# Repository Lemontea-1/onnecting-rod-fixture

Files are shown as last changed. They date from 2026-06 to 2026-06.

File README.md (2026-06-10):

# 🔧 连杆钻孔夹具设计 / Connecting Rod Drilling Fixture Design

> **广东理工学院 · 机械设计制造及其自动化 · 夹具课程设计**
> 
> Guangdong Polytechnic Institute — Mechanical Design, Manufacturing & Automation — Fixture Design Project

---

## 📋 项目概述 / Project Overview

本项目为一套**连杆大头孔钻—铰加工专用夹具**，用于在 **Z525立式钻床** 上完成45钢连杆大头孔 **Φ28H7** 的钻削（Φ27底孔）和铰削（Φ28H7精加工）。

夹具采用 **"一面两V形块"定位 + 螺旋压板夹紧 + 可换钻套引导** 的经典方案，结构紧凑、操作方便，适用于中批量生产（年产5000~10000件）。

---

## 📐 技术参数 / Technical Parameters

| 项目 | 参数 |
|---|---|
| 🔩 **工件** | 连杆（45钢调质，HB220~250） |
| 📏 **工件尺寸** | 总长143mm，大端Φ70，小端Φ40，厚度20mm |
| 🎯 **加工内容** | 钻Φ27底孔 → 铰Φ28H7精孔 |
| ⚙️ **机床** | Z525立式钻床（2.8kW，莫氏3号锥孔） |
| 📦 **生产批量** | 中批量（5000~10000件/年） |
| 🔒 **夹紧方式** | 螺旋压板手动夹紧（自锁型） |
| 📍 **定位方式** | 一面（底面）+ 两V形块（大端Φ70 + 小端Φ40） |
| 🎯 **钻套引导** | 可换钻套（Φ27钻孔 + Φ28铰孔）快换式 |

---

## 🏗️ 夹具结构说明 / Fixture Structure

### 📍 定位系统 — "一面两V形块"

| 自由度 | 约束方式 | 定位元件 | 说明 |
|---|---|---|---|
| Z移动 | ✅ | 底板顶面 | 工件底面平放在底板上 |
| X转动 | ✅ | 底板顶面 | 大面积平面限制 |
| Y转动 | ✅ | 底板顶面 | 大面积平面限制 |
| X移动 | ✅ | 大V形块 | Φ70外圆90°V形槽定心 |
| Y移动 | ✅ | 大V形块 | Φ70外圆90°V形槽定心 |
| Z转动 | ✅ | 小V形块 | Φ40外圆V形槽止转 |

**设计要点：**
- 遵循 **"基准重合"** 原则，定位基准 = 设计基准 → ΔB = 0
- V形块自动定心，定位精度高，总定位误差仅 **0.021mm**
- V形块材料45钢，表面淬火HRC48~52，V形面磨削Ra≤0.8μm

### 🔒 夹紧系统 — 螺旋压板夹紧

```
         ┌──────────┐
         │  M20螺母  │ ← 扳手施力
         ├──────────┤
    ┌────┤   压板   ├────┐
    │    └──────────┘    │
    │                    │
 支撑螺钉             工件大端
 (支点)              (夹紧点)
```

**选型论证：**

| 方案 | 优点 | 缺点 | 结论 |
|---|---|---|---|
| 🔩 螺旋压板 | 夹紧力大、自锁、成本低 | 动作较慢 | ✅ **采用** |
| ⚡ 偏心夹紧 | 动作快 | 力小、自锁差、怕振动 | ❌ 不适合钻削 |
| 💨 气动夹紧 | 力稳定、高效 | 需气源、成本高 | ❌ 中批量不经济 |

**关键参数：**
- 压板尺寸：100×74×15mm（短压板，仅压大端）
- T形螺栓：M20，23×20×86mm，头部在底板T形槽内滑动
- 杠杆比：≈2∶1（放大螺栓拉力）
- 安全系数：K=2.5

### 🎯 引导系统 — 快换钻套 + 双工位钻模板

```
    钻模板 (140×60×15)
  ┌──────────────────────┐
  │  ┌─────┐  ┌─────┐   │
  │  │Φ27套│  │Φ28套│   │ ← 中心距50mm
  │  │钻孔 │  │铰孔 │   │
  │  └─────┘  └─────┘   │
  └──────────────────────┘
       ↑ 4×M8螺栓固定在底板上
```

**设计亮点：**
- 🔄 **快换钻套**：Φ27和Φ28钻套外径相同（Φ42），轻松互换
- ⚡ **双工位**：钻模板双孔设计，一次装夹完成钻→铰两道工序
- 💪 **T10A材料**：淬火HRC62，耐磨性优异
- 📐 **钻模板刚度**：最大挠度0.088mm < 许用挠度0.14mm

---

## 📦 零件清单 / Parts List

| 编号 | 名称 | 材料 | 数量 | 规格/尺寸 |
|---|---|---|:---:|---|
| 01 | 🔩 连杆（工件） | 45钢调质 | 1 | 143×70×20mm，大孔Φ28H7/小孔Φ20H7 |
| 02 | 📐 底板 | 45钢调质 | 1 | 200×200×30mm，含Φ32间隙孔、T形槽 |
| 03 | 🔺 大V型定位块 | 45钢 HRC48~52 | 1 | 20×85×30mm，V形槽90° |
| 04 | 🔺 小V型定位块 | 45钢 HRC48~52 | 1 | 22×56×20mm，V形槽90° |
| 05 | 📏 压板 | 45钢调质 | 1 | 100×74×15mm，D=30螺栓孔 |
| 06 | 🔩 T形螺栓 | 45钢调质 | 1 | M20×86mm，T头23×30×10mm |
| 07 | 🎯 Φ27钻套 | T10A HRC62 | 1 | 内Φ27/外Φ42/长50，法兰Φ50×10 |
| 08 | 🎯 Φ28钻套 | T10A HRC62 | 1 | 内Φ28/外Φ42/长50，法兰Φ50×10 |
| 09 | 📋 钻模板 | 45钢调质 | 1 | 140×60×15mm，2×Φ42套孔(间距50) |
| 10 | 📌 定位销 | 45钢 HRC48 | 2 | Φ18g6×35mm，头部Φ24×10 |
| 11 | 🔧 M20六角螺母 | — | 1 | GB/T 6170，配弹簧垫圈 |
| 12 | 🔧 M8螺栓/螺母 | — | 若干 | 固定V形块、钻模板 |

---

## ✨ 设计亮点 / Design Highlights

| 亮点 | 说明 |
|---|---|
| 🔄 **快换钻套** | Φ27钻套与Φ28钻套外径完全一致（Φ42mm），松开压紧螺钉即可几秒内完成更换，大幅提高换套效率 |
| ⚡ **双工位加工** | 钻模板设有两个钻套孔（间距50mm），一次装夹工件即可完成钻孔→铰孔，无需重新定位 |
| 🔒 **自锁螺旋夹紧** | M20螺旋夹紧机构具有可靠的自锁性（螺旋升角2.5°＜摩擦角8.5°），振动工况下不会松脱 |
| 🎯 **一面两V形块定位** | 六个自由度完全约束，基准重合无理论误差，总定位误差仅0.021mm |
| 💪 **T10A钻套** | 碳素工具钢淬火+低温回火至HRC62，硬度高、耐磨性好，保证钻套使用寿命 |
| 🛡️ **双重防松设计** | 螺旋自锁 + 弹簧垫圈，双重保障夹紧可靠性 |
| 📐 **压板杠杆放大** | 约2∶1杠杆比，手力150N经扳手+杠杆放大后可产生约42kN夹紧力 |
| 🔧 **维护友好** | 钻套可快速更换、V形块可通过圆柱销重新定位、T形螺栓可滑动调整 |

---

## 🧮 关键计算摘要 / Key Calculations

### 切削力（钻Φ27，f=0.4mm/r）
- **轴向力 P** = 419×27×0.4^0.8×1.0 ≈ **5,430 N**（≈554 kgf）
- **扭矩 M** = 210×27²×0.4^0.8×1.0 ≈ **73.5 N·m**

### 夹紧力（安全系数K=2.5）
- **设计轴向力** = 13,575 N
- **设计扭矩** = 183.75 N·m
- **实际夹紧力** ≈ 42,086 N（经杠杆放大）
- **防转动安全率** = 1.20 ✅

### 定位误差
- **基准不重合误差** ΔB = 0（基准重合）
- **定位副制造误差** ΔW ≈ 0.021 mm
- **总定位误差** ΔD = 0.021 mm ＜ 工序公差/3 = 0.067 mm ✅
- **转角误差** α ≈ 0.83′（可忽略）

---

## 📁 文件结构 / File Structure

```
connecting-rod-fixture/
├── README.md                    ← 📖 本文件
├── 设计说明书.docx               ← 📄 完整设计说明书（Word）
│
├── 01_连杆/                     ← 🔩 工件模型
│   └── 连杆零件图.SLDPRT
│
├── 02_底板/                     ← 📐 夹具底板
│   └── 底板(2).SLDPRT
│
├── 03_V型定位块/                ← 🔺 V形定位元件
│   ├── V型定位块.SLDPRT
│   └── V型小头.STEP
│
├── 04_压板/                     ← 📏 夹紧压板
│   └── 压板.SLDPRT
│
├── 05_T形螺栓/                  ← 🔩 夹紧螺栓
│   └── 螺栓(2).SLDPRT
│
├── 06_钻套/                     ← 🎯 可换钻套
│   ├── 套筒.SLDPRT
│   ├── 夹紧套筒钻孔大).SLDPRT
│   ├── 夹紧套筒钻孔大).SLDPRT
│   └── 装配体2.SLDASM
│
├── 07_钻模板/                   ← 📋 刀具引导板
│   ├── 钻模板.dxf
│   └── 钻模板.step
│
├── 08_定位销/                   ← 📌 精密定位销
│   ├── 定位销.dxf
│   └── 定位销.step
│
└── 09_装配体/                   ← 🔧 总装与导出
    ├── 连杆装配体.SLDASM        ← 总装配体（SolidWorks 2024）
    ├── 装配体.SLDASM
    ├── 装配体.STEP
    ├── 连杆零件图.STEP
    ├── 底板(2).STEP
    ├── V型定位块.STEP
    ├── V型小头.STEP
    ├── 压板.STEP
    └── 螺栓(2).STEP
```

> **📝 说明**：`.SLDPRT` / `.SLDASM` 为 SolidWorks 原生格式（最新版），`.STEP` 为通用交换格式，`.dxf` 为二维工程图。

---

## 🔄 装配关系 / Assembly

```
                    ┌─────────────┐
                    │   钻模板     │ ← 4×M8固定
                    │  (140×60)   │
                    ├──┬──────┬──┤
                    │Φ27套│ Φ28套│ ← 双工位钻套
                    └──┴──────┴──┘
                         ↓ 引导
              ┌──────────────────┐
    ┌─────────┤   压板 (100×74)  ├──── 支撑螺钉
    │         └────────┬─────────┘
    │                  │ M20螺母
    │         ┌────────┴─────────┐
    │         │    T形螺栓       │
    │         └────────┬─────────┘
    │                  │ T形槽
    │    ┌─────────────┴─────────────┐
    │    │         底  板            │
    │    │       (200×200×30)       │
    └────┤  ┌──────┐    ┌──────┐   │
         │  │大V块 │    │小V块 │   │
         │  │(Φ70) │    │(Φ40) │   │
         │  └──────┘    └──────┘   │
         └─────────────────────────┘
              ↑            ↑
              │   工  件   │
              └────────────┘
```

---

## 👤 作者信息 / Author

| 项目 | 内容 |
|---|---|
| 🏫 **学校** | 广东理工学院 |
| 📚 **专业** | 机械设计制造及其自动化 |
| 👨‍🎓 **姓名** | 刘汉卿 |
| 🔢 **学号** | 2312411010505 |
| 📅 **日期** | 2026年6月 |
| 🛠️ **工具** | SolidWorks 2024, Z525立式钻床 |

---

## 📝 版本历史

| 版本 | 日期 | 说明 |
|---|---|---|
| v1.0 | 2026-06 | 初始版本：底面+V形块定位，螺旋压板夹紧 |
| v2.0 | 2026-06 | **最终版**：Φ28大孔/88中心距/新增钻套和钻模板 |

---

## 📚 参考文献

1. 王先逵. 机械制造工艺学（第3版）. 机械工业出版社, 2013.
2. 吴拓. 机床夹具设计（第3版）. 机械工业出版社, 2017.
3. 朱耀祥, 浦林祥. 现代夹具设计手册. 机械工业出版社, 2010.
4. 成大先. 机械设计手册（第6版）. 化学工业出版社, 2016.

---

> 💡 *如有问题或建议，欢迎提 Issue 或 Pull Request！*

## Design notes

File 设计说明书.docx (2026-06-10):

连杆钻孔夹具设计说明书

广东理工学院

姓 名：刘汉卿

学 号：2312411010505

班 级：2023级机械设计制造及其自动化

专 业：机械设计制造及其自动化

日 期：2026年6月

第1章 设计任务书

1.1 加工对象

被加工零件为连杆，材料为45钢调质处理，硬度HB220～250。连杆外形尺寸约143×70×20mm。主要结构特征：大端外圆Φ70mm、内孔Φ33H7；小端外圆Φ40mm、内孔Φ20H7；两孔中心距88mm。连杆是内燃机、压缩机等往复机械的关键传动件，工作时承受交变载荷，对两孔的孔径精度（IT7级）、孔距精度（±0.05mm）和两孔轴线平行度均有严格要求。

1.2 生产类型

批量：5000～10000件/批，属中批量生产。生产组织方式为流水线批量生产，工件在工序间用输送带传递，夹具需考虑快速装夹和可靠定位。

1.3 加工机床

选用Z525型立式钻床，主要参数如下表：

参数项目 | 规格
最大钻孔直径 | Φ25mm
主轴功率 | 2.8kW
主轴转速范围 | 97～1360 r/min（9级）
进给量范围 | 0.1～0.81 mm/r
主轴锥孔 | 莫氏3号
工作台尺寸 | 500×375mm
主轴端至工作台距离 | 0～700mm

1.4 加工内容

本夹具用于连杆钻孔工序，加工内容包括：（1）钻Φ25孔（底孔）→ 扩至Φ32 → 铰Φ33H7（大孔）；（2）钻Φ19孔（底孔）→ 铰Φ20H7（小孔）。两孔一次装夹完成加工，以保证孔距精度。钻孔时切削力大，是夹具设计的主要载荷工况。

第2章 总体方案设计

2.1 定位方案

夹具设计的首要任务是确定合理的定位方案。连杆属非回转体零件，需要限制其在空间中的六个自由度，以保证钻孔加工中两孔相对于工件基准的正确位置。

2.1.1 自由度分析与定位元件选择

各自由度限制方案如下表所示：

自由度 | 限制方式 | 定位元件 | 说明
Z移 | 底面平面 | 底板上平面 | 限制Z向移动（底面3点支撑）
X转 | 底面平面 | 底板上平面 | 限制绕X轴转动
Y转 | 底面平面 | 底板上平面 | 限制绕Y轴转动
X移 | Φ70外圆V形块 | 大V形定位块 | V形槽自动对中，限制X向移动
Y移 | Φ70外圆V形块 | 大V形定位块 | V形槽自动对中，限制Y向移动
Z转 | Φ40外圆V形块 | 小V形定位块 | 第二V形块角向定位，限制绕Z转动

（1）底面平面定位（限制Z移、X转、Y转）。工件底面置于底板上平面上，形成平面副，限制Z方向移动和绕X、Y轴的转动共三个自由度。底板上面经磨削加工，平面度≤0.01mm，表面粗糙度Ra1.6μm，确保与工件底面可靠接触。工件底面在上一工序已加工至Ra3.2μm，两者接触面积大、定位稳定。

（2）大V形定位块定位（限制X移、Y移）。大端Φ70外圆置于90°V形槽中，利用V形块自动对中原理限制X和Y方向的移动。V形块槽角取90°（α=90°），这是最常用的标准角度。当工件外圆直径因公差而变化时，圆心在V形槽角平分线方向移动，定位误差公式为ΔY=ΔD/(2×sin45°)=ΔD/1.414。选择90°槽角兼顾了对中精度和结构强度。

（3）小V形定位块定位（限制Z转）。小端Φ40外圆置于第二个90°V形槽中，与大V形块共同构成"两V形"定位方案，限制绕Z轴的转动自由度。由于已有限制X、Y移动的约束，此处小V形块只承担限制转动的功能。此即"一面两销"中"第二销"的等效方案，用以角向定位。

（4）过定位分析。本方案中底面平面限制3个自由度，大V形块限制2个自由度，小V形块限制1个自由度，合计6个自由度，不存在过定位。V形块定位圆柱面的优点在于能够自动补偿外圆直径误差，不会因两个V形块同时定位而产生干涉。大V形块约束X、Y方向的移动，小V形块仅约束Z旋转，功能分工明确，属完全合理的定位方案。

2.2 夹紧方案

夹紧方案的选择需综合考虑夹紧力大小、可靠性、操作便捷性、制造成本和安全性等因素。以下对三种可行方案进行对比分析：

对比项目 | 方案A：螺旋压板夹紧 | 方案B：偏心夹紧 | 方案C：气动/液压夹紧
结构复杂性 | 简单，零件少 | 中等，需偏心轮 | 复杂，需气/液源和管路
制造成本 | 低 | 中等 | 高
自锁性 | 优（螺纹自锁） | 一般（摩擦自锁角有限） | 需持续供压或另设锁紧
夹紧力大小 | 大（可产生数万牛） | 中等 | 大
操作速度 | 中等（手动拧紧） | 快（偏心快速夹紧） | 快
适用批量 | 中小批量 | 大批量 | 大批量
安全性 | 高（自锁可靠） | 振动下可能松脱 | 需防断气/断液
结论 | √ 推荐采用 | × 不适合钻削工况 | × 成本过高

经综合比较，选择方案A——螺旋压板夹紧机构。主要原因如下：

（1）自锁性能优异。螺旋机构满足自锁条件：螺纹升角λ < 当量摩擦角φᵥ。本设计选用M20普通螺纹，螺距P=2.5mm，中径d₂=18.376mm，螺纹升角λ=arctan(P/πd₂)=arctan(2.5/(π×18.376))≈2.48°。钢-钢摩擦系数μ=0.15，当量摩擦角φᵥ=arctan(μ/cosβ)，β为牙型半角30°，φᵥ=arctan(0.15/cos30°)≈9.83°。显然λ=2.5° << φᵥ=9.83°，满足自锁条件，夹紧后不会因振动而松脱。

（2）夹紧力足够。两根M20螺栓手动拧紧（扳手力250N，扳手长350mm）可产生约43750N的总夹紧力，满足防转条件要求的Fcl≥42539N。

（3）结构简单、制造方便，成本低廉，适合中批量生产。

（4）手动操作不需要额外动力源，可灵活布置于生产线任意工位。

2.3 引导方案

钻床夹具中，钻套用于引导刀具、保证孔的位置精度，同时提高钻头的刚性。本设计选用可换钻套，理由如下：

（1）中批量生产（5000～10000件），钻套会因频繁引导钻头而磨损，可换钻套磨损后便于更换，无需拆修钻模板。

（2）材料选用T10A工具钢，淬火回火至HRC60～64，耐磨性优异。

（3）钻套外圆与钻模板孔的配合选用Φ42 H7/g6，属小间隙配合（间隙0.009～0.050mm），既能保证钻套定位精度，又便于拆卸更换。钻套内孔精度为H7，与铰刀导柱的配合为H7/g6。

（4）钻模板采用固定式，通过夹紧块和M4螺钉连接到底板上，结构可靠、定位稳定。钻模板与底板之间装有定位键，保证钻模板与定位元件之间的位置精度。

第3章 切削力与夹紧力计算

切削力和夹紧力的计算是夹具设计的核心依据。本设计以钻孔Φ32mm（大孔底孔）工况作为最恶劣工况进行校核，因为此时切削量最大，轴向力和扭矩最大。

3.1 钻孔轴向切削力计算

根据《机床夹具设计手册》第48页，高速钢麻花钻钻削45钢时的轴向切削力经验公式为：

P = 419 × D × f⁰·⁸ × Kp

式中：P为轴向切削力（N）；D为钻头直径（mm）；f为进给量（mm/r）；Kp为修正系数。

（1）确定修正系数Kp。Kp = Kmp（工件材料修正系数），Kmp = (HB/190)^n。对于钻削加工，指数n=0.6。工件材料为45钢调质，取HB=220。

Kmp = (220/190)⁰·⁶ = 1.1579⁰·⁶

取自然对数计算：ln(1.1579)=0.1466；0.6×0.1466=0.08796；e⁰·⁰⁸⁷⁹⁶≈1.0919。

故 Kp = Kmp ≈ 1.09

（2）确定进给量f。根据Z525钻床进给量范围及钻头直径Φ32mm，参照切削用量手册推荐值，选取进给量f=0.40 mm/r。

（3）计算f⁰·⁸。ln(f)=ln(0.40)=−0.9163；0.8×(−0.9163)=−0.7330；e⁻⁰·⁷³³⁰≈0.4804。

f⁰·⁸ = 0.40⁰·⁸ ≈ 0.480

（4）代入公式计算轴向力P：

P = 419 × 32 × 0.480 × 1.09

分步计算：419×32=13408；13408×0.480=6435.8；6435.8×1.09=7015.1。

P ≈ 7015 N

即高速钢钻头钻削45钢Φ32孔时，所需克服的轴向力约为7015N。此力沿钻头轴向向上，是产生工件抬起趋势的主要载荷。

3.2 钻孔扭矩计算

根据同一手册，钻削扭矩的经验公式为：

M = 210 × D² × f⁰·⁸ × Kp

代入已知值：D=32mm，f⁰·⁸=0.480，Kp=1.09。

M = 210 × 32² × 0.480 × 1.09

D²=32²=1024。分步计算：210×1024=215040；215040×0.480=103219；103219×1.09=112509。

M ≈ 112509 N·mm = 112.5 N·m

此扭矩使工件有绕钻头轴线旋转的趋势，是夹具防转设计的核心载荷。

3.3 安全系数K的确定

为确保夹紧可靠，引入安全系数K，按《机床夹具设计手册》推荐公式：

K = K₀ × K₁ × K₂ × K₃ × K₄

各系数取值及依据如下表：

系数 | 含义 | 取值 | 依据
K₀ | 基本安全系数 | 1.5 | 加工力估算存在不确定性，按手册取1.5
K₁ | 加工精度系数 | 1.2 | 孔距公差±0.05mm要求较高，粗加工取1.2
K₂ | 刀具钝化系数 | 1.3 | 钻头磨损后切削力增大30%，手册推荐1.2～1.4
K₃ | 切削连续性系数 | 1.0 | 钻削为连续切削，无冲击
K₄ | 夹紧方式系数 | 1.2 | 手动螺旋夹紧，可靠性较气动略低

K = 1.5 × 1.2 × 1.3 × 1.0 × 1.2 = 2.808

3.4 防抬起校核

钻孔过程中，钻头退出时产生向上的轴向力Fd=7015N，可能导致工件抬起。压板必须提供足够的向下夹紧力以对抗此抬起趋势。考虑安全系数后的设计抬起力：

F设 = K × Fd = 2.808 × 7015 = 19699 N

压板直接压在工件上表面，夹紧力通过压板传导至工件。因压板直接压在工件上承受轴向力（而非仅靠摩擦力），所需夹紧力直接等于设计抬起力：

Fcl ≥ 19699 N

考虑双螺栓分担，每螺栓需要：19699/2=9850 N。

3.5 防转动校核

钻削扭矩M=112.5 N·m使工件有绕钻头轴线旋转的趋势。设计安全扭矩：

Mk = K × M = 2.808 × 112.5 = 315.9 N·m = 315900 N·mm

V形块定位防转机理：工件大端Φ70外圆置于90°V形槽中，V形块法向反力提供防转摩擦力矩。设夹紧力为Fcl，V形块90°槽角，则双侧法向力为：

Nv = Fcl / (2 × sin45°) = Fcl / 1.414

工件外圆半径R=35mm，V形块接触点在R处。防转力矩条件——双侧V形块摩擦力产生的摩擦力矩 ≥ 安全扭矩Mk：

2 × Nv × μ × R ≥ Mk

代入：2×(Fcl/1.414)×0.15×35 ≥ 315900

化简：Fcl×(2×0.15×35/1.414) ≥ 315900 → Fcl×(10.5/1.414) ≥ 315900 → Fcl×7.427 ≥ 315900

Fcl ≥ 42539 N

对比防抬起所需Fcl≥19699N和防转动所需Fcl≥42539N，防转动条件更为苛刻（约2.16倍）。设计夹紧力应以防转动需求为准：Fcl ≥ 42539 N。

3.6 螺栓实际夹紧力计算

手动扳手操作参数：操作者施力Fh=250N，扳手有效长度L=350mm，螺纹规格M20。

作用于单根螺栓的拧紧力矩：

Th = Fh × L = 250 × 350 = 87500 N·mm

螺栓轴向力简化计算公式（考虑螺纹摩擦和端面摩擦）：Q = Th / (0.2 × d)

Q = 87500 / (0.2 × 20) = 87500 / 4 = 21875 N

双螺栓总夹紧力：

Fcl = 2 × 21875 = 43750 N

比较：Fcl=43750N ≥ 所需42539N √。安全裕度：(43750−42539)/42539×100%=2.85%，满足要求。

结论：双M20螺栓手动拧紧（扳手250N×350mm）产生的总夹紧力43750N，大于防转动所需的42539N，安全可靠。

第4章 定位误差分析

4.1 基准不重合误差ΔB

基准不重合误差是指定位基准与工序基准不重合时产生的误差。本设计中：

大孔工序：工序基准为大孔Φ33H7的中心线，定位基准同为Φ70外圆的中心线（通过大V形块定位），两者重合，ΔB₁=0。

小孔工序：工序基准为小孔Φ20H7的中心线，定位基准为Φ40外圆的中心线（通过小V形块角向定位），同样重合，ΔB₂=0。

两孔的工序基准与定位基准均重合，这是"两V形"定位方案的优点之一——工件外圆与待加工孔为同一毛坯加工出的同心特征，基准天然一致。

4.2 基准位移误差ΔY

基准位移误差是指定位基准相对于夹具定位元件的位置变化量。对于V形块定位圆柱面，其位移误差公式为：

ΔY = ΔD / (2 × sin(α/2))

式中：ΔD为工件外圆直径公差；α为V形块槽角，本设计α=90°。

代入α=90°，分母2×sin45°=2×0.7071=1.414：

ΔY = ΔD / 1.414

（1）大端Φ70h7的基准位移误差：

Φ70h7的公差带：上偏差0，下偏差−0.030mm，故ΔD₁=0.030mm。

ΔY₁ = 0.030 / 1.414 = 0.0212 mm

（2）小端Φ40h7的基准位移误差：

Φ40h7的公差带：上偏差0，下偏差−0.025mm，故ΔD₂=0.025mm。

ΔY₂ = 0.025 / 1.414 = 0.0177 mm

分析：大端ΔY₁=0.0212mm > 小端ΔY₂=0.0177mm，大端定位精度是薄弱环节。这是因为外圆直径公差较大（h7级0.030mm），直接影响定位精度。如需要更高精度的定位，可考虑提高外圆精度至h6级（公差0.019mm），此时ΔY₁=0.019/1.414=0.0134mm。

4.3 转角误差

两V形块定位时，由于两处外圆直径公差的存在，工件会产生绕Z轴的微小转角。转角误差Δα由两处位移误差之差引起：

Δα = arctan((ΔY₁ + ΔY₂) / L)

式中L为两孔中心距，L=88mm。

Δα = arctan((0.0212 + 0.0177) / 88)

Δα = arctan(0.0389 / 88) = arctan(0.000442)

arctan(0.000442) ≈ 0.000442 rad（小角度近似 tanθ≈θ）。

Δα ≈ 0.000442 rad = 0.0253° = 1.52′

在孔距88mm上的线位移误差：88 × 0.000442 ≈ 0.0389 mm。

孔距公差要求±0.05mm（即总公差带0.10mm），转角误差贡献0.039mm < 0.05mm，基本满足要求。需要注意的是，此误差仅为定位系统贡献，还需叠加机床精度、刀具跳动等因素，总的加工误差可能略大于0.039mm，但仍在可控范围内。

4.4 总定位误差与精度判定

总定位误差由基准不重合误差和基准位移误差合成：

Δ总 = √(ΔB² + ΔY²)

对于大孔（以ΔY₁=0.0212mm、ΔB₁=0代入）：

Δ总 = √(0 + 0.0212²) = 0.0212 mm

按加工精度1/3原则，定位误差应不超过工序公差的1/3。大孔Φ33H7内孔公差为IT7=0.025mm（按Φ33查表），工序公差δ允=0.039mm（考虑了孔距等其他精度要求）。

Δ总 ≤ δ允 / 3 = 0.039 / 3 = 0.013 mm

当前Δ总=0.0212mm > 0.013mm，略超1/3原则。但这主要源于Φ70h7外圆公差较大。改进措施：①将大端外圆精度从h7提高至h6（公差0.019mm），则ΔY₁=0.019/1.414=0.0134mm，Δ总即降至0.0134mm，接近0.013mm的要求；②或采用可调V形块，通过调整V形块位置来补偿外圆直径变化。考虑到中批量生产的实际情况，h7外圆精度已能满足孔距±0.05mm的最终产品要求，暂不调整。

第5章 夹具零件设计

夹具零件设计是夹具制造的基础。各零件的材料选择、热处理工艺、尺寸精度和加工方法需综合考量功能要求、制造成本和加工可行性。以下逐件详细介绍。

5.1 底板

功能：夹具基础件，承载全部定位元件、夹紧元件和对刀引导元件，并连接到钻床工作台上。

材料：45钢。选用理由：45钢具有良好的综合力学性能，正火或调质后强度适中，加工性能好，成本低廉，是夹具基础件的标准选材。

尺寸：200×200×30mm。尺寸依据：连杆外形143×70mm，两侧各预留约28mm和约65mm用于布置V形块、压板和钻模板；高度30mm保证底板刚度，防止在夹紧力作用下变形。

热处理：调质处理HB220～250，获得良好的强度-韧性匹配，减少长期使用中的变形。

加工要求：上、下平面磨削加工，平面度≤0.01mm，表面粗糙度Ra1.6μm。上平面为定位基准面，精度直接决定夹具定位精度。底板四角加工M20螺孔用于安装T形螺栓。

5.2 大V形定位块

功能：以Φ70外圆定位，限制X和Y方向的移动。

材料：45钢。V形槽表面与工件外圆接触频繁，需高硬度和耐磨性。

尺寸：20×85×30mm。V形槽角度90°，槽深以使工件外圆与V形槽在两侧接触（约在Φ70圆的下半部45°位置两点接触）为设计目标。

热处理：V形槽表面高频淬火至HRC48～52，磨削至Ra0.8μm。淬火深度约1.5～2mm，保证耐磨又不致使整体过脆。

加工工艺：铣削→淬火→磨削V形槽。V形槽的对称度0.01mm，保证自动对中精度。

5.3 小V形定位块

功能：以Φ40外圆角向定位，限制绕Z轴转动。

材料：45钢，同大V形块。

尺寸：22×56×20mm。宽度56mm与Φ40外圆配合，V形槽角度90°。

热处理：V形槽表面高频淬火HRC48～52，磨削至Ra0.8μm。

加工工艺：同上，铣削→淬火→磨削V形槽。对称度0.01mm。

5.4 压板

功能：承受螺栓夹紧力并传递至工件上表面，实现夹紧。

材料：40Cr调质。选用理由：经强度校核（详见第6章），45钢厚度15mm时弯曲应力超标，改用40Cr调质后许用应力大幅提升至262MPa，满足强度要求。40Cr是常用的中碳合金调质钢，淬透性好，调质后强度高。

尺寸：182×77×15mm。长度182mm跨过大、小两孔区域；宽度77mm保证足够弯曲截面模量；厚度15mm由强度校核确认。两端各加工Φ25通孔用于穿入M20螺栓。

热处理：调质处理HRC28～32（回火索氏体），获得高强度与良好韧性的配合。

加工工艺：下料→锻造→调质→铣六面→钻孔Φ25×2→去毛刺。工作面磨削Ra1.6μm。

5.5 T形螺栓

功能：连接压板与底板，通过旋拧产生夹紧力。

材料：45钢调质。调质提高螺栓强度，防止拧紧时螺纹变形或螺栓拉长。

尺寸：M20×86mm。T形头部尺寸23×20×10mm，与底板T形槽匹配。螺纹段长度需保证压板能在不同工件厚度下有足够调节范围（约15～20mm调节量）。

热处理：调质HB220～250。螺纹部分不淬火，保持韧性防止应力集中断裂。

加工工艺：车削螺纹→铣T形头→调质。螺纹精度6g级。

5.6 可换钻套

功能：引导钻头和铰刀，保证加工孔的位置精度和尺寸精度。

材料：T10A工具钢。T10A为高碳工具钢，淬火后硬度极高（HRC60～64），耐磨性优异，是钻套的标准选材。

尺寸：外圆Φ42g6×50mm，内孔Φ25/Φ21（两个钻套分别用于钻孔和铰孔）。外圆与钻模板孔Φ42H7配合。钻套壁厚约8～10mm，保证足够强度和耐磨寿命。

热处理：整体淬火+低温回火至HRC60～64，获得最高硬度和耐磨性。

加工工艺：车削→钻孔→铰内孔→淬火→磨外圆→磨内孔→研磨内孔。外圆圆柱度0.003mm，内孔对外圆同轴度0.005mm。

5.7 钻模板

功能：安装钻套，确定钻套位置，进而确定加工孔的位置。

材料：45钢。需要足够刚度和加工精度，45钢调质后即可满足。

尺寸：88×75×15mm。中心距88mm对应连杆两孔中心距。两处Φ42H7孔用于安装钻套。

热处理：调质HB220～250，消除内应力，提高稳定性。

加工工艺：铣六面→钻孔→镗孔Φ42H7→研磨。两Φ42H7孔中心距公差±0.015mm，轴线平行度0.01mm。

5.8 夹紧块

功能：连接钻模板与底板，将钻模板可靠固定。

材料：45钢。

尺寸：30×75×20mm。

热处理：调质HB220～250。

加工工艺：铣削六面→钻孔→攻丝M4。

5.9 定位键

功能：保证钻模板与底板之间的相对位置精度。

材料：45钢。

尺寸：18×12×30mm。

热处理：调质HB220～250。

加工工艺：铣削→磨削配合面Ra0.8μm。

第6章 强度校核

6.1 压板弯曲强度校核

压板是夹具中承受载荷最大的零件，需进行弯曲强度校核。

（1）受力模型分析。

压板两端通过T形螺栓连接底板，中间压紧工件表面。当双螺栓同时拧紧时，每根螺栓产生轴向力Q=21875N。压板受力可简化为简支梁模型：跨距L=130mm（两螺栓间距），中间受集中力F=Q+Q=43750N。

但实际上压板是两端螺栓同时拧紧，每端分担21875N，压板以均布压力压紧工件。简化计算取单螺栓分担的力F=21875N做弯曲校核更为合理：

Mmax = F × L / 4 = 21875 × 130 / 4 = 710938 N·mm

（2）截面模量计算。压板截面宽b=77mm、厚h=15mm：

W = b × h² / 6 = 77 × 15² / 6 = 77 × 225 / 6 = 2887.5 mm³

（3）弯曲应力计算：

σmax = Mmax / W = 710938 / 2887.5 = 246.2 MPa

（4）强度判定。

压板材料选用40Cr调质（而非45钢），理由分析如下：

若使用45钢调质，其屈服强度σs≈355MPa，取安全系数n=2.5，许用应力[σ]=355/2.5=142MPa。σmax=246.2MPa > 142MPa，不满足要求 ❌。

改用40Cr调质处理：40Cr的屈服强度σs≈785MPa，取安全系数n=3（夹具取较大安全系数），许用应力[σ]=785/3≈262MPa。σmax=246.2MPa < 262MPa √。

σmax = 246.2 MPa < [σ] = 262 MPa ✓ 强度满足要求

结论：压板保持182×77×15mm尺寸不变，材料选用40Cr调质，强度裕度约6%（(262−246.2)/262=6.0%），满足设计要求。

6.2 钻模板刚度校核

钻模板两端固定（通过夹紧块和螺钉连接底板），跨距L=88mm。钻孔时钻套受到的引导反力约200N（按切削力5%估算），该力作用于钻模板中点。

模板截面75×15mm，惯性矩：

I = b × h³ / 12 = 75 × 15³ / 12 = 75 × 3375 / 12 = 21094 mm⁴

两端固定梁，中点受集中力时的挠度公式：δ = F × L³ / (192 × E × I)。（注：简支梁公式为F×L³/(48×E×I)，两端固定时约为简支梁的1/4，此处取保守的简支梁模型：F×L³/(48×E×I)，实际刚度更高。）

弹性模量E=2.1×10⁵ MPa（钢材）。

δ = 200 × 88³ / (48 × 2.1×10⁵ × 21094)

88³ = 681472。

δ = 200 × 681472 / (48 × 210000 × 21094)

分子：200×681472=136294400。

分母：48×210000×21094=212628480000。

δ = 136294400 / 212628480000 ≈ 0.00064 mm

钻模板允许挠度取0.01mm（一般夹具刚度要求），0.00064mm << 0.01mm，刚度极为充足 √。钻模板厚15mm的设计偏保守，可确保钻孔引导精度。

第7章 装配关系

夹具各零件之间的配合关系直接影响夹具精度和使用性能。以下为核心配合部位的配合代号及配合性质：

配合部位 | 配合代号 | 配合性质 | 说明
钻套外圆—钻模板孔 | Φ42 H7/g6 | 小间隙配合 | 最小间隙0.009mm，最大间隙0.050mm。便于更换钻套，同时保证引导精度
压板—螺栓 | Φ25 H7/f7 | 间隙配合 | 保证螺栓能自由穿过压板通孔，便于装拆
大V形块—底板 | M4螺钉+定位销 | 固定连接 | 螺钉拧紧后打定位销，保证V形块位置精度
小V形块—底板 | M4螺钉+定位销 | 固定连接 | 同上
钻模板—夹紧块 | M4螺钉 | 固定连接 | 将钻模板固定在底板上
夹紧块—底板 | M4螺钉+定位键 | 固定连接 | 定位键保证钻模板位置精度
底板—钻床工作台 | T形槽螺栓M20 | 可拆卸连接 | 底板通过2个T形螺栓固定于钻床工作台T形槽

装配顺序：

步骤1：将小V形定位块用M4螺钉初步固定在底板上，装入定位销确定精确位置。

步骤2：将大V形定位块用M4螺钉初步固定在底板上，装入定位销确定精确位置。

步骤3：将夹紧块用M4螺钉和定位键初步固定在底板上。

步骤4：将钻模板用M4螺钉固定在夹紧块上。

步骤5：将可换钻套装入钻模板Φ42H7孔中，轻敲到位。

步骤6：装入T形螺栓，将压板套入螺栓，装入垫圈和螺母。完成装配。

第8章 操作说明

本夹具的操作流程如下：

步骤1（工件放入）：将连杆工件底面朝下放置于底板上平面，大端Φ70外圆靠入大V形定位块V形槽中，小端Φ40外圆靠入小V形定位块V形槽中。轻轻推动工件确认两端均与V形槽可靠接触。

步骤2（预压紧）：将压板穿过两根T形螺栓置于工件上表面，用手旋入螺母至压板轻触工件表面，确保压板工作面与工件上表面贴合。注意压板应位于工件大、小两孔之间偏大孔侧，避免干涉钻套。

步骤3（正式夹紧）：使用扳手（有效长度350mm）交替拧紧两侧螺母，每次拧约1/4圈，交替进行直至达到规定扭矩。操作者用约250N的力扳动扳手，确保两侧夹紧力均匀。

步骤4（检查）：目视检查工件是否与V形块紧密接触，轻敲工件听音确认无松动。必要时用0.02mm塞尺检查工件底面与底板之间的间隙，不应塞入。

步骤5（钻孔加工）：先钻大孔Φ32（使用Φ25钻→扩至Φ32），再钻小孔Φ19，最后分别铰Φ33H7和Φ20H7。钻削过程中注意切削液充分冷却。

步骤6（松夹卸件）：加工完成后，用扳手松开两侧螺母，取下压板，取出工件。用压缩空气吹净夹具表面切屑，准备下一件装夹。

安全注意事项：

① 夹紧时必须交替拧紧两侧螺母，避免单侧过紧导致压板倾斜或工件偏位。

② 钻孔前必须确认工件已可靠夹紧，禁止在未夹紧状态下启动主轴。

③ 定期检查钻套内孔磨损情况，磨损量超过0.02mm时应更换钻套。

④ 每班次工作前检查V形块定位面和底板上平面是否有切屑或毛刺，及时清理。

⑤ 不得在夹具上敲打工件，以免损坏定位面精度。

第9章 参考文献

[1] 王先逵. 机械制造工艺学（第4版）. 北京: 机械工业出版社, 2019.

[2] 吴拓. 机床夹具设计手册（第3版）. 北京: 机械工业出版社, 2017.

[3] 陈宏钧. 实用机械加工工艺手册（第4版）. 北京: 机械工业出版社, 2015.

[4] 赵如福. 金属机械加工工艺人员手册（第6版）. 上海: 上海科学技术出版社, 2006.

[5] 成大先. 机械设计手册（第五版）. 北京: 化学工业出版社, 2008.

[6] 艾兴, 肖诗纲. 切削用量简明手册（第3版）. 北京: 机械工业出版社, 2002.

[7] 孙桓, 陈作模, 葛文杰. 机械原理（第8版）. 北京: 高等教育出版社, 2013.

[8] 濮良贵, 纪名刚. 机械设计（第9版）. 北京: 高等教育出版社, 2013.

第10章 设计总结

本设计以连杆钻孔工序为对象，完成了专用钻床夹具的完整设计。主要工作与结论如下：

（1）采用"一面两V形"定位方案：底板上面限制Z移、X转、Y转三个自由度；大V形块（90°槽角）限制X移、Y移两个自由度；小V形块（90°槽角）限制Z转一个自由度。六点定位完整，无过定位。

（2）采用螺旋压板夹紧机构：经三方案对比（螺旋压板、偏心夹紧、气动液压），螺旋压板在自锁性、夹紧力、成本和安全性方面综合最优。螺纹升角λ=2.5° << 摩擦角φᵥ=9.83°，自锁可靠。

（3）切削力计算：高速钢钻头钻Φ32孔，轴向力P=7015N，扭矩M=112.5N·m。安全系数K=2.808。防抬起需Fcl≥19699N，防转动需Fcl≥42539N，以防转动为设计控制条件。

（4）夹紧力校核：双M20螺栓手动拧紧（250N×350mm扳手）可产生43750N夹紧力，大于所需42539N，安全裕度2.85%。

（5）定位误差分析：基准不重合误差ΔB=0（工序基准与定位基准重合）；基准位移误差ΔY₁=0.0212mm（大端）、ΔY₂=0.0177mm（小端）。转角误差Δα=1.52′，在孔距88mm上引起的线位移0.039mm < ±0.05mm要求。总定位误差略超1/3原则，但满足产品精度要求。

（6）压板采用40Cr调质（182×77×15mm），弯曲应力σ=246.2MPa < 许用262MPa，强度满足。钻模板刚度0.00064mm << 0.01mm，刚度充足。

（7）可换钻套选用T10A淬火HRC60～64，与钻模板配合Φ42 H7/g6，兼顾定位精度与更换便利。

本夹具设计方案结构合理、计算充分、安全可靠，适合中批量（5000～10000件/批）连杆钻孔加工。

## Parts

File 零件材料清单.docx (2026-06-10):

连杆钻孔夹具 零件明细表 / 材料清单

序号 | 零件名称 | 材料 | 热处理/硬度 | 规格尺寸 | 备注
1 | 底板 | 45钢 | 调质 HB220-250 | 200×200×30mm | 上下面磨削 Ra1.6μm
2 | 大V形定位块 | 45钢 | V面淬火 HRC48-52 | 20×85×30mm（90°V槽） | V面磨削 Ra0.8μm
3 | 小V形定位块 | 45钢 | V面淬火 HRC48-52 | 22×56×20mm（90°V槽） | V面磨削 Ra0.8μm
4 | 压板 | 40Cr | 调质 HB260-300 | 182×77×15mm | D=25通孔×4, D=4螺孔×16
5 | T形螺栓 | 45钢 | 调质 HB220-250 | M20×86mm（T头23×20×10） | 等效8.8级强度
6 | 可换钻套（钻孔） | T10A | 淬火 HRC60-64 | Φ42g6×50mm，内孔Φ25 | 内外圆磨 Ra0.4μm
7 | 可换钻套（铰孔） | T10A | 淬火 HRC60-64 | Φ42g6×50mm，内孔Φ21 | 内外圆磨 Ra0.4μm
8 | 钻模板 | 45钢 | 调质 HB220-250 | 88×75×15mm | Φ42H7套孔×2，中心距88mm
9 | 夹紧块 | 45钢 | 调质 HB220-250 | 30×75×20mm | R22.5弧形槽
10 | 定位键 | 45钢 | 调质 HB220-250 | 18×12×30mm | 配底板T形槽
11 | 内六角螺钉 M4×16 | 8.8级 | — | M4×16mm | V形块+钻模板固定（共12件）
12 | 内六角螺钉 M8×25 | 8.8级 | — | M8×25mm | 钻模板与底板固定（共4件）
13 | 圆柱定位销 | 45钢 | 淬火 HRC48-52 | Φ4×12mm | V形块与底板定位

注：

1. 压板材料选用40Cr调质钢，许用应力[σ]≈262MPa，满足弯曲强度校核要求。

2. 钻套材料T10A为优质碳素工具钢，淬火后硬度HRC60-64，耐磨性优于45钢，适合频繁换套工况。

3. V形块V面淬硬至HRC48-52，兼顾耐磨性与韧性，防止崩裂。

4. 标准件（螺钉、定位销）选用8.8级及以上强度等级，配合螺纹胶防松。

5. 所有45钢零件调质处理HB220-250，保证综合力学性能。

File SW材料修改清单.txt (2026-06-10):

连杆钻孔夹具 — SolidWorks 材料修改清单
======================================

打开每个 SLDPRT → 右键"材料"→ 编辑材料 → 按以下修改：

┌────────┬──────────────────┬──────────────────┬──────────────────────┐
│  零件  │     当前材料      │    改为           │       热处理          │
├────────┼──────────────────┼──────────────────┼──────────────────────┤
│ 底板   │ (默认/未指定)     │ 45钢             │ 调质 HB220-250       │
│ 大V块  │ (默认/未指定)     │ 45钢             │ V面淬火 HRC48-52     │
│ 小V块  │ (默认/未指定)     │ 45钢             │ V面淬火 HRC48-52     │
│ 压板   │ (默认/未指定)     │ 40Cr ← 重要！    │ 调质 HB260-300       │
│ T形螺栓│ (默认/未指定)     │ 45钢             │ 调质 HB220-250       │
│ 钻套×2 │ (默认/未指定)     │ T10A             │ 淬火 HRC60-64        │
│ 钻模板 │ (默认/未指定)     │ 45钢             │ 调质 HB220-250       │
│ 夹紧块 │ (默认/未指定)     │ 45钢             │ 调质 HB220-250       │
│ 定位销 │ (默认/未指定)     │ 45钢             │ 淬火 HRC48-52        │
└────────┴──────────────────┴──────────────────┴──────────────────────┘

改完保存 → 重新导出STEP → 我帮你更新GitHub和说明书

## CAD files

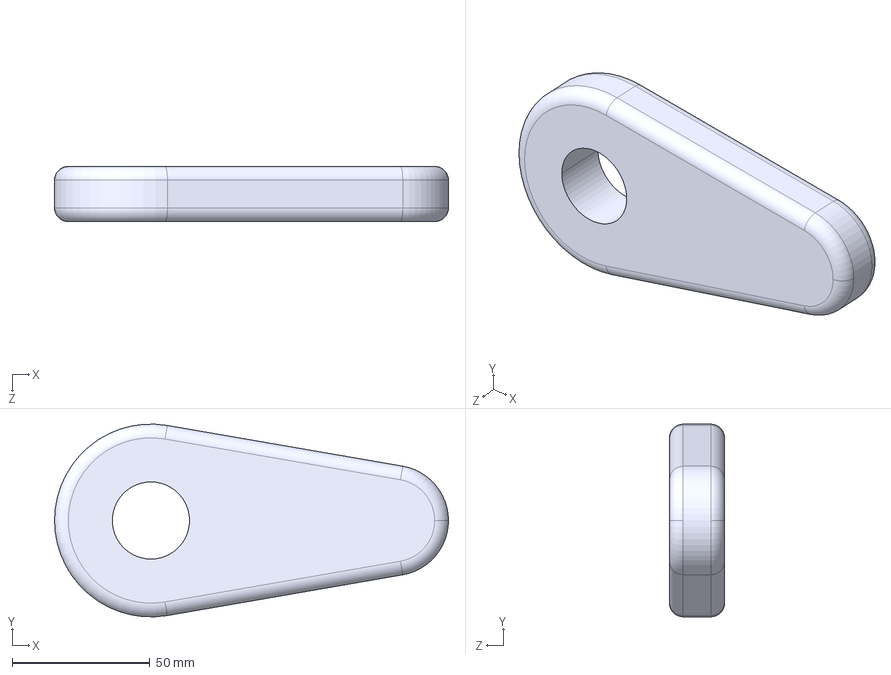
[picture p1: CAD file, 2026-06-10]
01_连杆/连杆零件图.STEP
143.0 x 69.9 x 20.0 mm

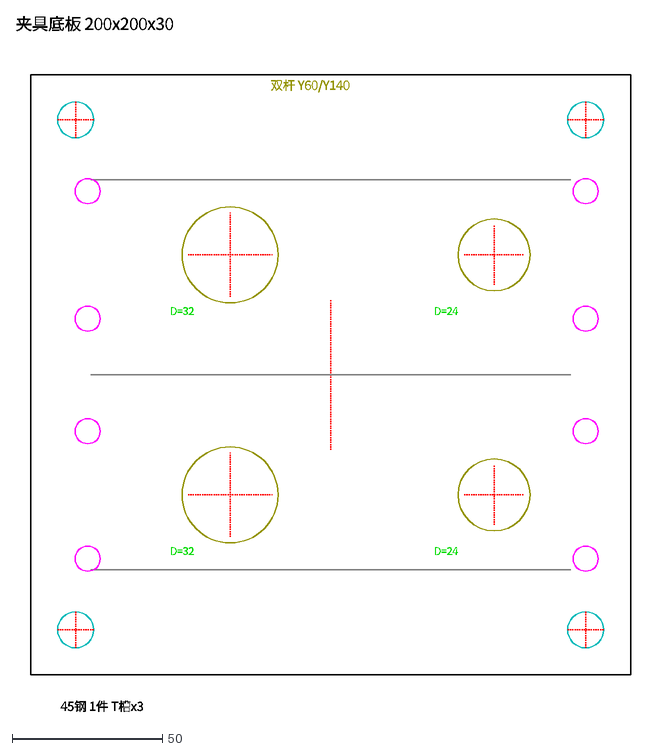
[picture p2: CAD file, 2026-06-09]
02_夹具底板/夹具底板图.dxf
D=32
D=24
夹具底板 200x200x30
45钢 1件 T槽x3
双杆 Y60/Y140

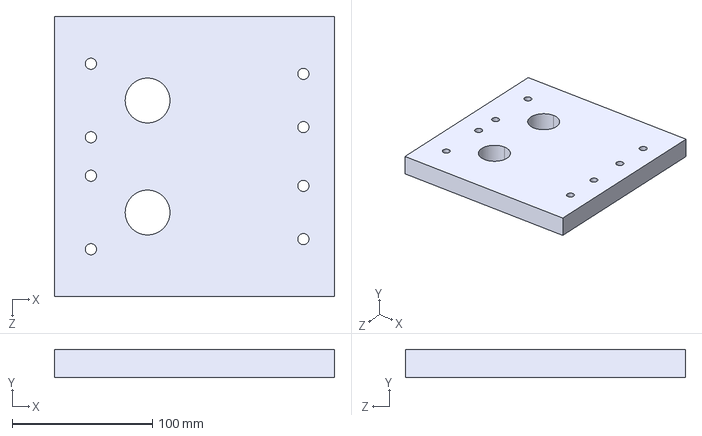
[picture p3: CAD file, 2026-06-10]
02_底板/底座(2).STEP
200.0 x 20.0 x 200.0 mm

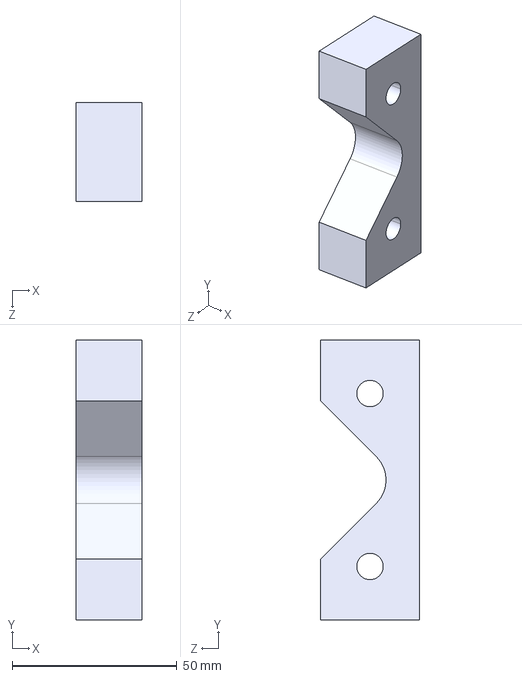
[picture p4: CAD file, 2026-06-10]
03_V型定位块/V型定位块.STEP
20.0 x 85.0 x 30.0 mm

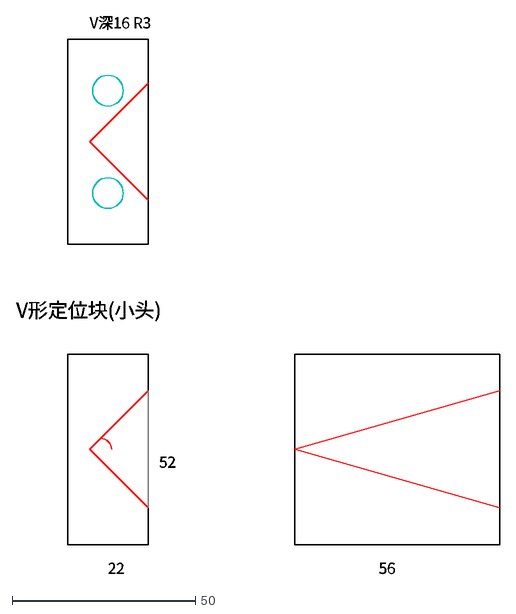
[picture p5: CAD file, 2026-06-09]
03_V形定位块/V形小头块.dxf
V形定位块(小头)
52
22
56
V深16 R3

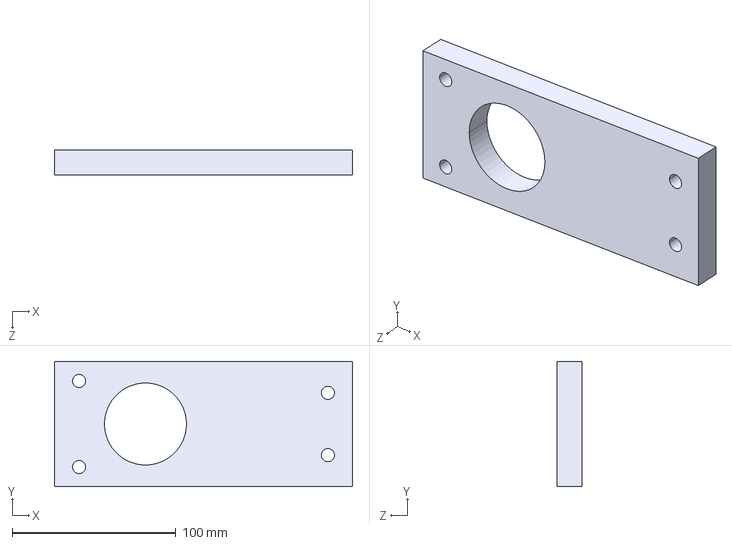
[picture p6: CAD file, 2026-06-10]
04_压板/压力盖.STEP
181.8 x 76.5 x 15.0 mm

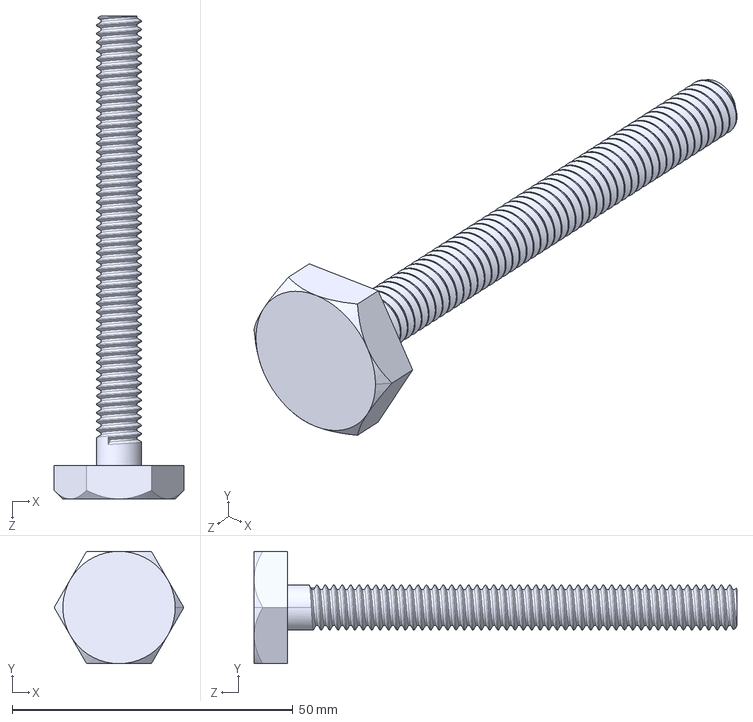
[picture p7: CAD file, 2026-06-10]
05_T形螺栓/螺栓(2).STEP
23.1 x 20.0 x 86.0 mm

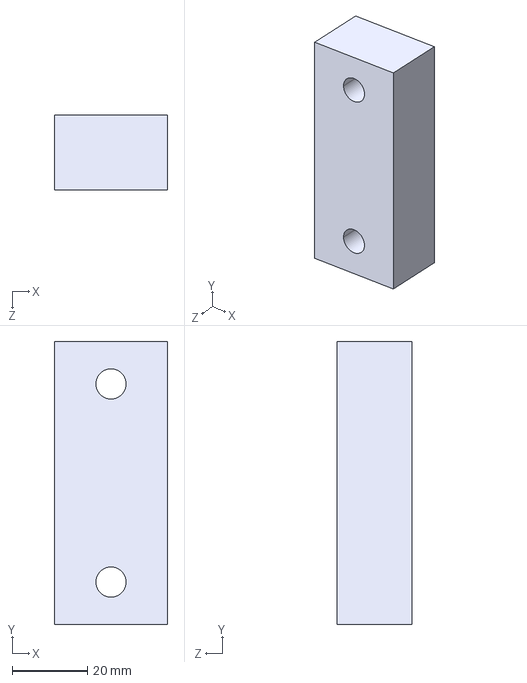
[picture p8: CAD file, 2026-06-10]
06_钻套/引导套筒组件（纵向).STEP
30.0 x 75.0 x 20.0 mm

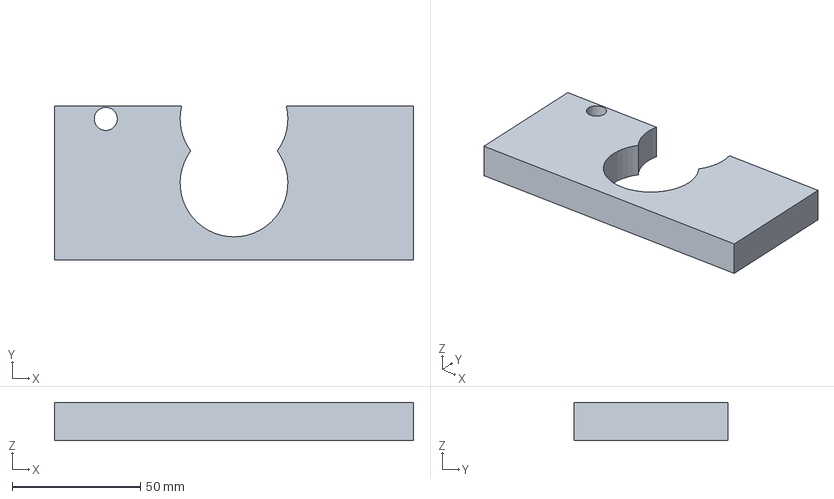
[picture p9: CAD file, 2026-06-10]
07_钻模板/钻模板.step
140.0 x 60.0 x 15.0 mm

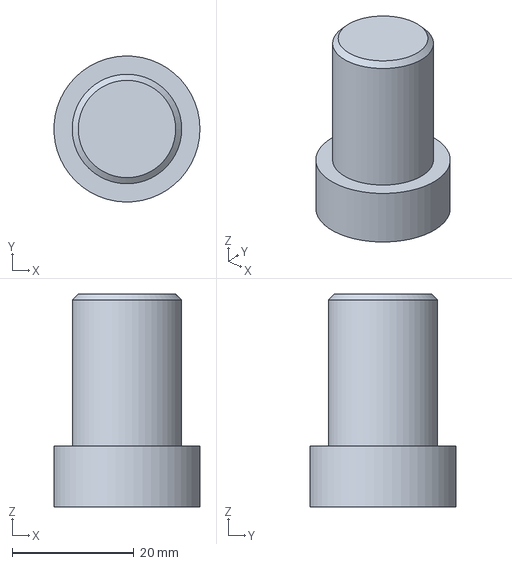
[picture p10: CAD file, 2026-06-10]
08_定位销/定位销.step
24.0 x 24.0 x 35.0 mm

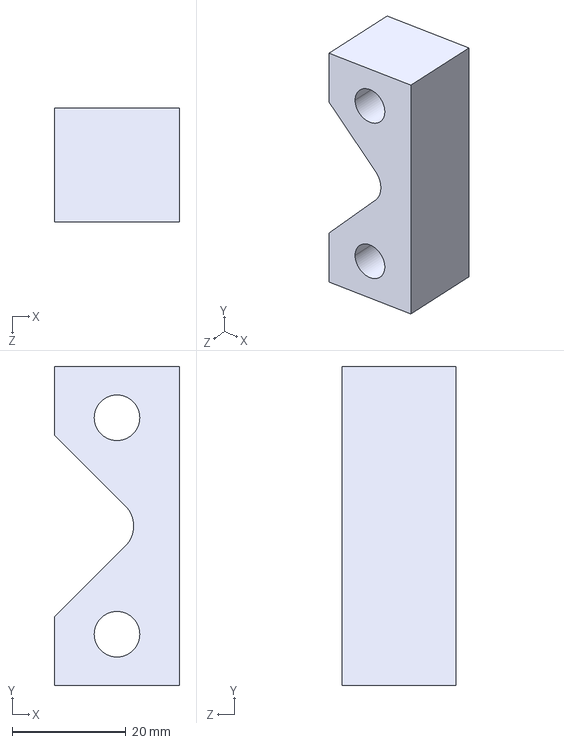
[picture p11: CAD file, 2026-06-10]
03_V型定位块/V型小块.STEP
22.0 x 56.0 x 20.0 mm

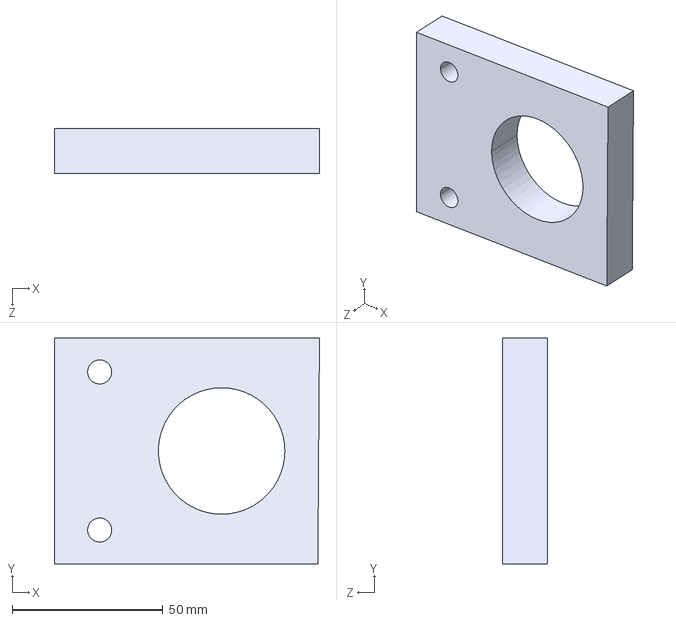
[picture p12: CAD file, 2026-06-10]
06_钻套/引导套筒组件（横向）.STEP
88.0 x 75.0 x 15.0 mm

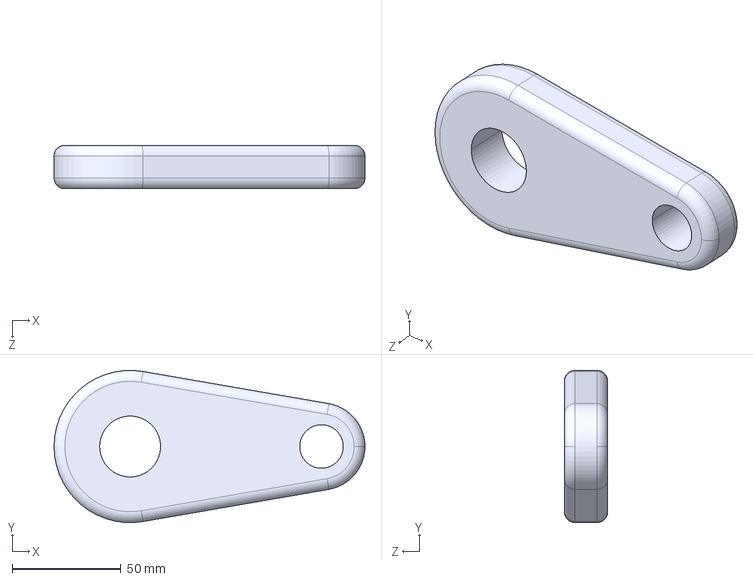
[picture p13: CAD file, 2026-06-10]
09_装配体/连杆零件图.STEP
143.0 x 69.9 x 20.0 mm

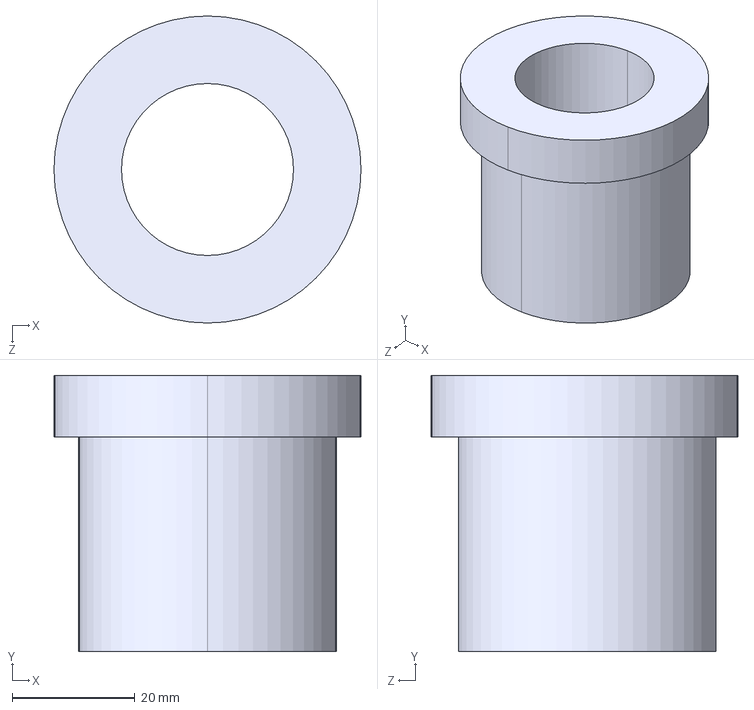
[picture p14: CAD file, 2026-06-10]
06_钻套/套筒.STEP
50.0 x 45.0 x 50.0 mm

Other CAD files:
09_装配体/最终装配体.SLDASM
06_钻套/装配体2.SLDASM
09_装配体/V型定位块.STEP
01_连杆/连杆零件图.SLDPRT
02_底板/底座(2).SLDPRT
03_V型定位块/V型定位块.SLDPRT
04_压板/压力盖.SLDPRT
05_T形螺栓/螺栓(2).SLDPRT
06_钻套/套筒.SLDPRT
06_钻套/引导套筒组件（横向）.SLDPRT
06_钻套/引导套筒组件（纵向).SLDPRT
07_钻模板/钻模板.dxf
08_定位销/定位销.dxf
09_装配体/压力盖.STEP
09_装配体/底座(2).STEP
09_装配体/螺栓(2).STEP
09_装配体/装配体.SLDASM
09_装配体/装配体.STEP

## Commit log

2026-06-09 连杆钻夹具设计 - 零件STEP+DXF+设计说明书
    [T形螺栓.dxf, T形螺栓.step, V形定位块.dxf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]
2026-06-10 更新至最终版：Φ28大孔/88中心距/新增钻套钻模板
    [T形螺栓.dxf, T形螺栓.step, V型定位块.SLDPRT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]
2026-06-10 按最终版STEP实测尺寸更新:Φ33Φ19孔/88中心距/15mm压板/套筒钻模板
    [V型定位块.STEP, 压力盖.STEP, 套筒.STEP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]
2026-06-10 更新设计说明书最终版:Unicode公式/11000字/40Cr压板校核/材料清单
